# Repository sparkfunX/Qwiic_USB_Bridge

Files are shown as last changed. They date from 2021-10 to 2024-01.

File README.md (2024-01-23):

SparkFun Qwiic USB Development Kit - SAMD21
========================================

Qwiic USB Development Kit - SAMD21 (https://www.sparkfun.com/products/24639)

[*Qwiic USB Development Kit - SAMD21 (SPX-24639)*](https://www.sparkfun.com/products/24639)

The Qwiic USB Development kit is designed for folks that want to interface a Qwiic device quickly and easily to a computer. The core processor is the SAM21 which allows quick (hah!) and seamless serial printing over USB, as well as easy development and programming using the Arduino environment. The professional printed enclosure makes the device easy to plug/unplug as well as allowing Qwiic boards to be mounted to the enclosure itself.

The development kit features two Qwiic connectors and a user-addressable WS2812 LED. In case you need more IO, there are four GPIO pins, accessible by removing the enclosure, two of which are ADC pins. This little device is not only a great tool for making compact prototypes, but a handy way to add Qwiic sensors to your PC-based projects.

Repository Contents
-------------------

* **/Documentation** - Data sheets, additional product information
* **/Enclosure** - Enclosure files 
* **/Firmware** - Example code 
* **/Hardware** - Eagle design files (.brd, .sch)
* **/Production** - Production panel files (.brd)

License Information
-------------------

This product is _**open source**_! 

Please review the LICENSE.md file for license information. 

If you have any questions or concerns on licensing, please contact technical support on our [SparkFun forums](https://forum.sparkfun.com/viewforum.php?f=152).

Distributed as-is; no warranty is given.

- Your friends at SparkFun.

_<COLLABORATION CREDIT>_

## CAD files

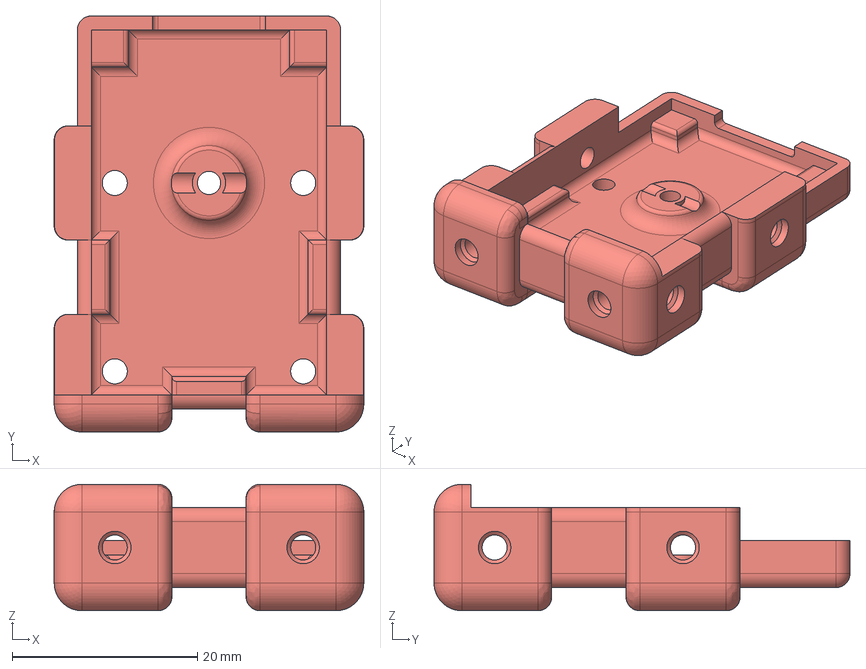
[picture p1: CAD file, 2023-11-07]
Mechanical/Solids/BODY.step
33.4 x 44.9 x 13.6 mm

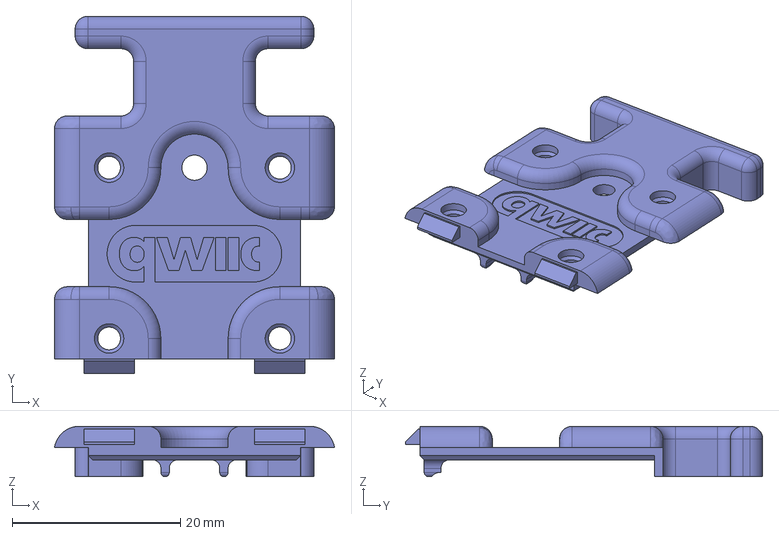
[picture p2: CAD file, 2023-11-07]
Mechanical/Solids/LID.step
33.3 x 42.5 x 6.00 mm

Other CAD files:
Mechanical/Qwiic_USB_Bridge_3DP v28.f3z
Mechanical/Solids/Body.stl
Mechanical/Solids/Lid.stl

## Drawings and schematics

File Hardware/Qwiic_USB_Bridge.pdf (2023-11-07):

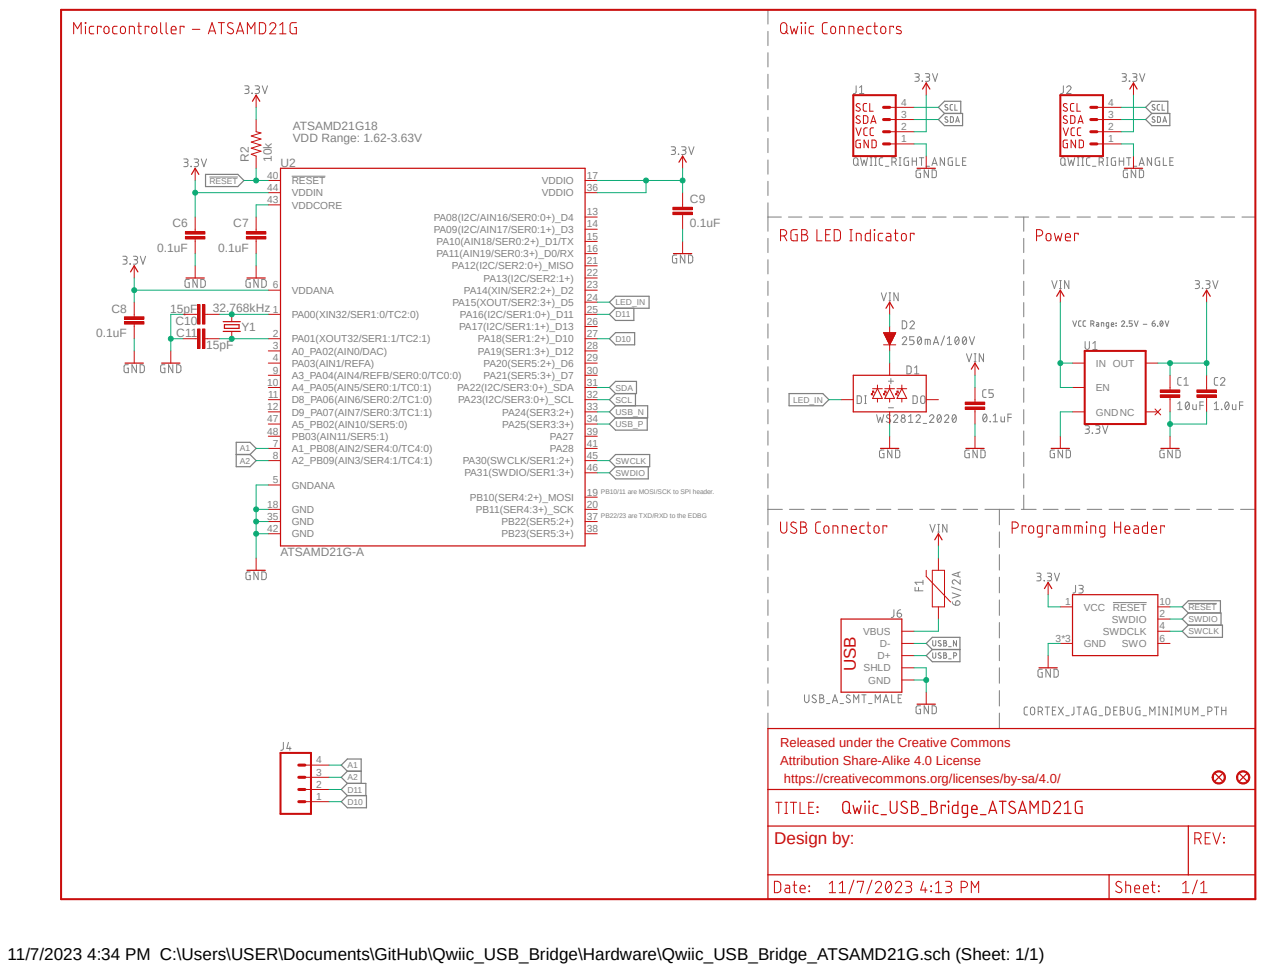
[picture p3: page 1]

PB10/11 are MOSI/SCK to SPI header.

PB22/23 are TXD/RXD to the EDBG

Released under the Creative Commons
Attribution Share-Alike 4.0 License
https://creativecommons.org/licenses/by-sa/4.0/

11/7/2023 4:34 PM C:\Users\USER\Documents\GitHub\Qwiic_USB_Bridge\Hardware\Qwiic_USB_Bridge_ATSAMD21G.sch (Sheet: 1/1)

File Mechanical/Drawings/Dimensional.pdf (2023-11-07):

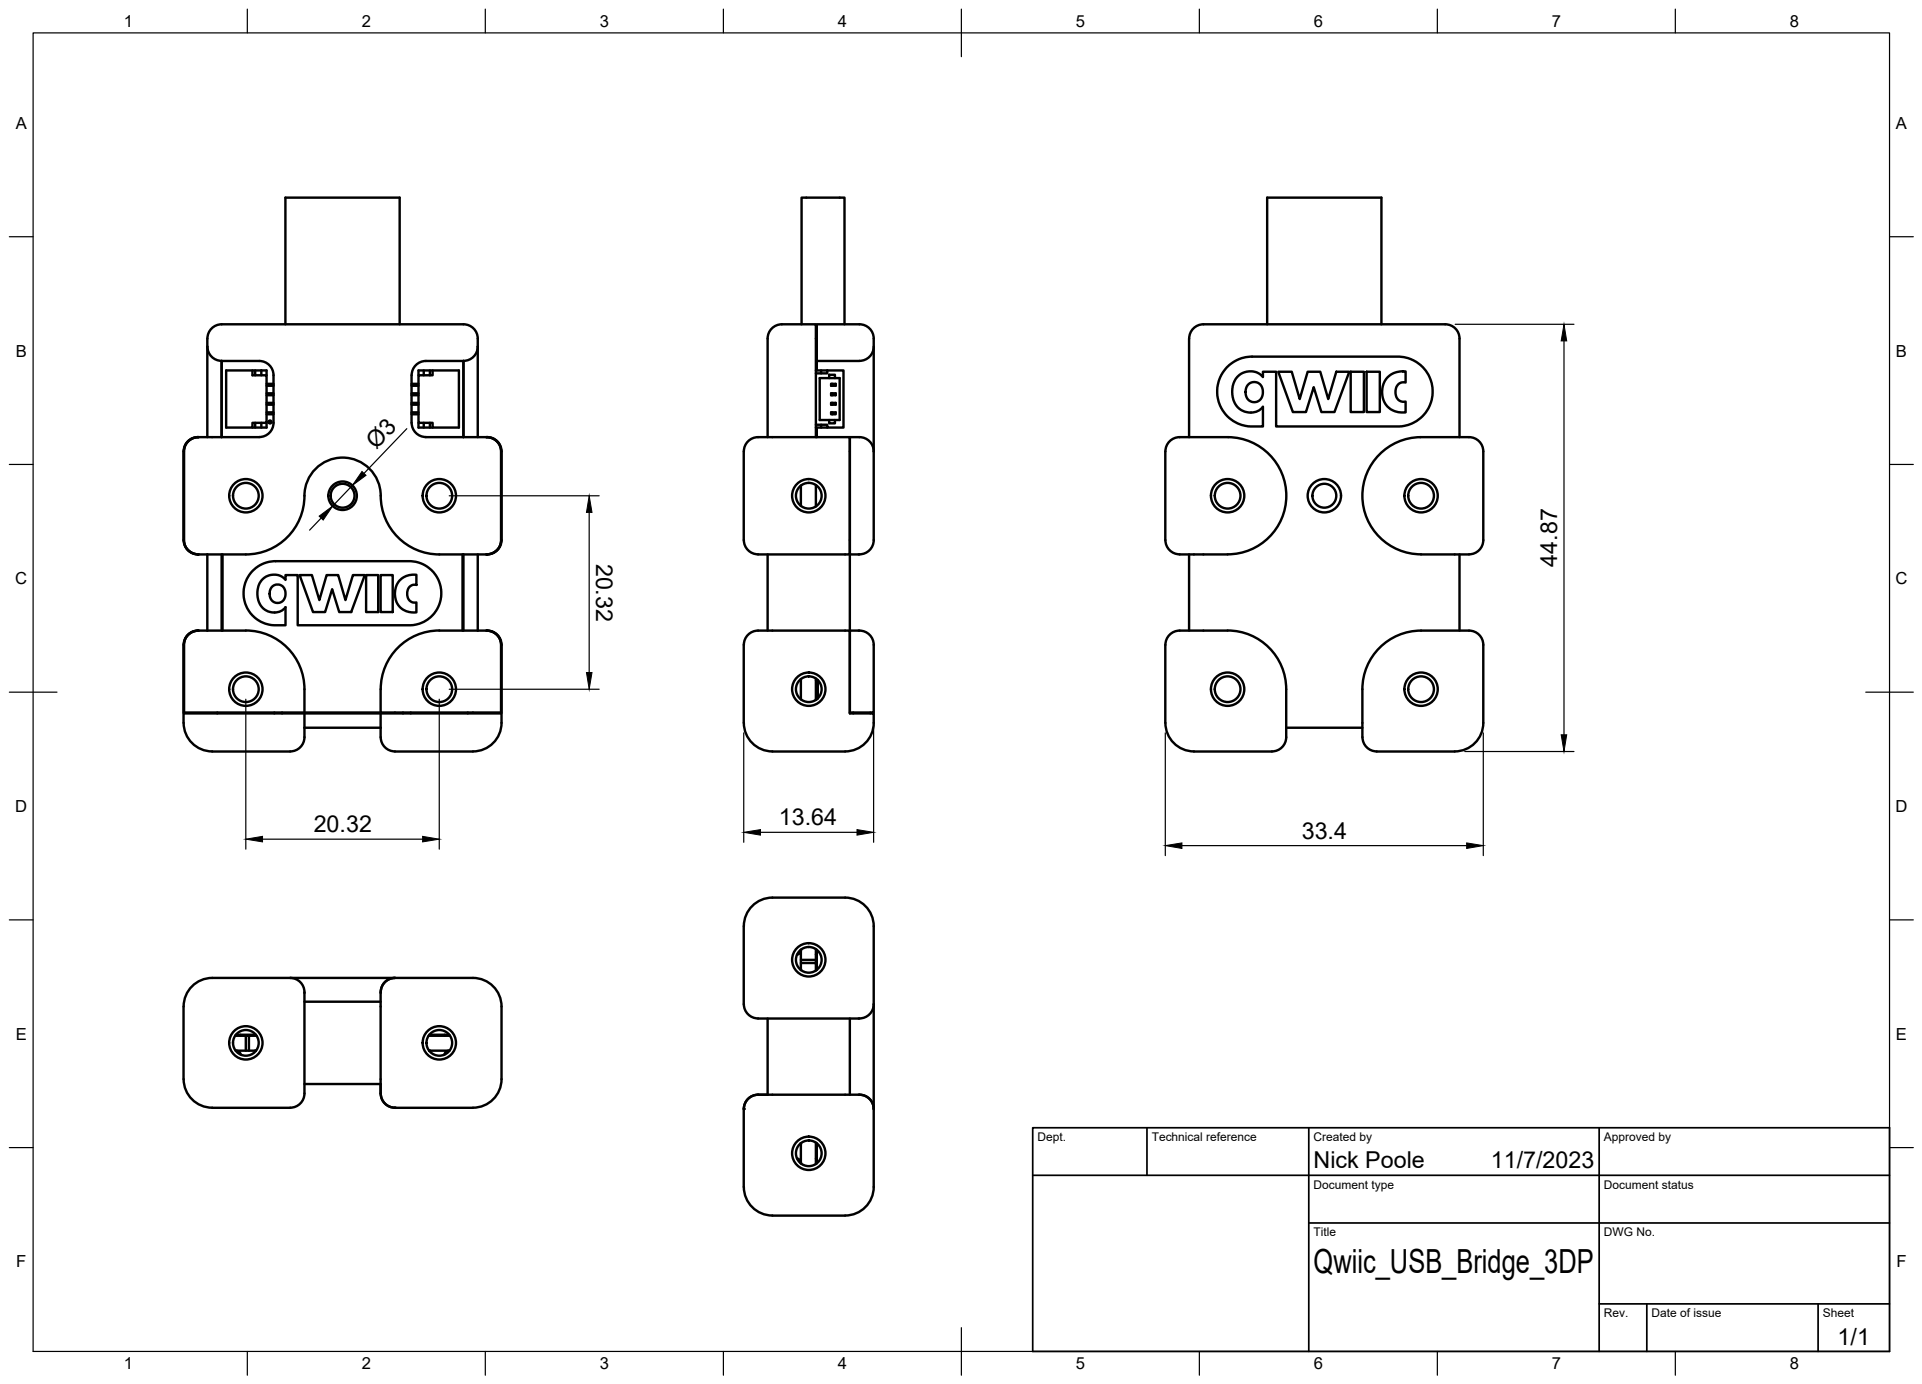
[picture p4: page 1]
Title; DWG No.; Rev.; Date of issue; Sheet

Dept. | Technical reference | Created by Nick Poole 11/7/2023 | Approved by

Document type | Document status

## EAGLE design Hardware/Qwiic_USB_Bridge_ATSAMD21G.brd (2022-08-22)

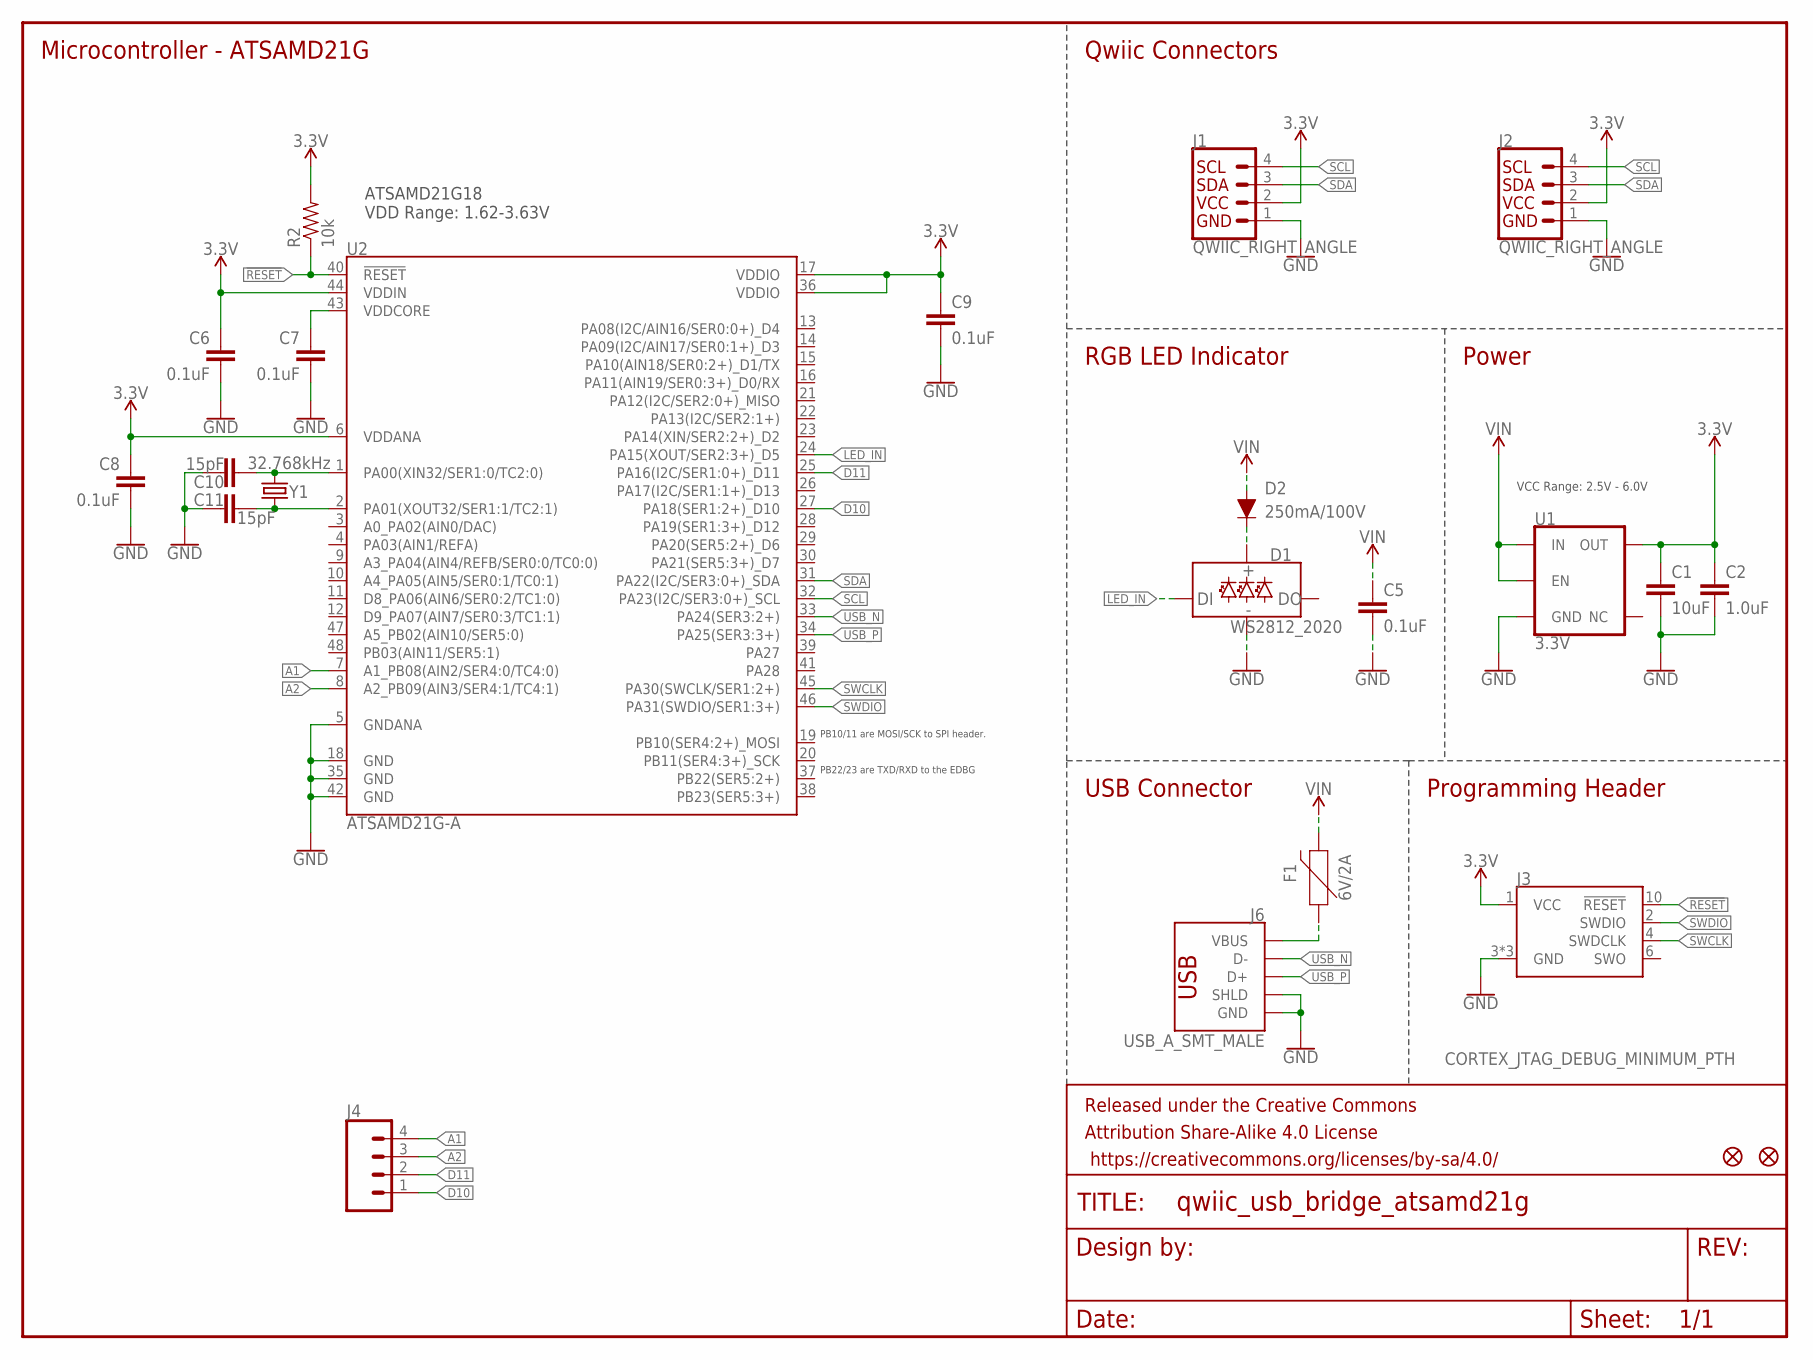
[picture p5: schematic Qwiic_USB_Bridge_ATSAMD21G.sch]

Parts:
C1: 10uF; 0603
C2: 1.0uF; 0603
C5, C6, C7, C8, C9: 0.1uF; 0603
C10, C11: 15pF; 0603
D1: WS2812_2020; WS2812-2020
D2: 250mA/100V; SOD-323
F1: 6V/2A; 1210
FD1, FD2: FIDUCIALUFIDUCIAL; FIDUCIAL-MICRO
FRAME2: FRAME-LETTER; CREATIVE_COMMONS
J1, J2: QWIIC_RIGHT_ANGLE; JST04_1MM_RA
J3: CORTEX_JTAG_DEBUG_MINIMUM_PTH; 2X5-PTH-1.27MM
J4: CONN_041X04_NO_SILK; 1X04_NO_SILK
J6: USB_A_SMT_MALE; USB-A-SMT-MALE
R2: 10k; 0603
U1: 3.3V; SOT23-5
U2: ATSAMD21G-A; TQFP-48
Y1: 32.768kHz; CRYSTAL-SMD-3.2X1.5MM

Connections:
3.3V: C1.1, C2.1, C6.1, C8.1, C9.1, J1.2, J2.2, J3.1 (VCC), R2.2, U1.5 (OUT), U2.6 (VDDANA), U2.17 (VDDIO), U2.36 (VDDIO), U2.44 (VDDIN)
!RESET: J3.10 (!RESET), R2.1, U2.40 (!RESET!)
A1: J4.4, U2.7 (A1_PB08(AIN2/SER4:0/TC4:0))
A2: J4.3, U2.8 (A2_PB09(AIN3/SER4:1/TC4:1))
D10: J4.1, U2.27 (PA18(SER1:2+)_D10)
D11: J4.2, U2.25 (PA16(I2C/SER1:0+)_D11)
GND: C1.2, C2.2, C5.2, C6.2, C7.2, C8.2, C9.2, C10.1, C11.2, D1.GND, J1.1, J2.1, J3.3 (GND), J3.5 (GND), J3.9 (GND), J6.GND1 (GND), J6.SHLD1 (SHLD), J6.SHLD2 (SHLD), U1.2 (GND), U2.5 (GNDANA), U2.18 (GND), U2.35 (GND), U2.42 (GND)
LED_IN: D1.DI, U2.24 (PA15(XOUT/SER2:3+)_D5)
unnamed: F1.1, J6.VBUS1 (VBUS)
unnamed: D1.VCC, D2.C
unnamed: C10.2, U2.1 (PA00(XIN32/SER1:0/TC2:0)), Y1.P$2 (2)
unnamed: C11.1, U2.2 (PA01(XOUT32/SER1:1/TC2:1)), Y1.P$1 (1)
SCL: J1.4, J2.4, U2.32 (PA23(I2C/SER3:0+)_SCL)
SDA: J1.3, J2.3, U2.31 (PA22(I2C/SER3:0+)_SDA)
SWCLK: J3.4 (SWDCLK), U2.45 (PA30(SWCLK/SER1:2+))
SWDIO: J3.2 (SWDIO), U2.46 (PA31(SWDIO/SER1:3+))
USB_N: J6.D-1 (D-), U2.33 (PA24(SER3:2+))
USB_P: J6.D+1 (D+), U2.34 (PA25(SER3:3+))
VDDCORE1: C7.1, U2.43 (VDDCORE)
VIN: C5.1, D2.A, F1.2, U1.1 (IN), U1.3 (EN)

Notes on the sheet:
Qwiic Connectors
RGB LED Indicator
Power
Microcontroller - ATSAMD21G
VCC Range: 2.5V - 6.0V
USB Connector
Programming Header
PB22/23 are TXD/RXD to the EDBG
PB10/11 are MOSI/SCK to SPI header.
ATSAMD21G18 VDD Range: 1.62-3.63V

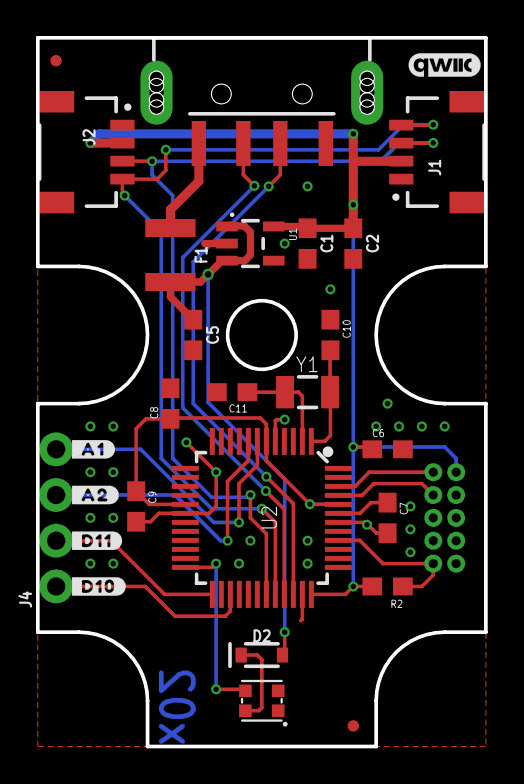
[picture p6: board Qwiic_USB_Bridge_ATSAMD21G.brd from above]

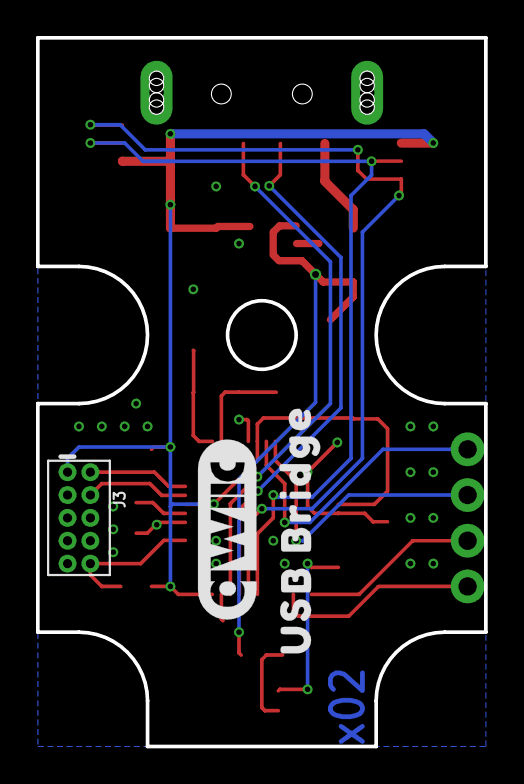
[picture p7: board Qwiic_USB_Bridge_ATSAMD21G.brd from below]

Board: 2 copper layers, 24.9 x 39.4 mm, 31 parts (3 on the bottom side), 20 nets.

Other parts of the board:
U$1: #_A1#0
U$2: #_A2#0
U$3: #_D11#0
U$4: #_D10#0
U$7: QWIIC_10MM
U$8: USB_BRIDGE0
U$9: QWIIC_4MM

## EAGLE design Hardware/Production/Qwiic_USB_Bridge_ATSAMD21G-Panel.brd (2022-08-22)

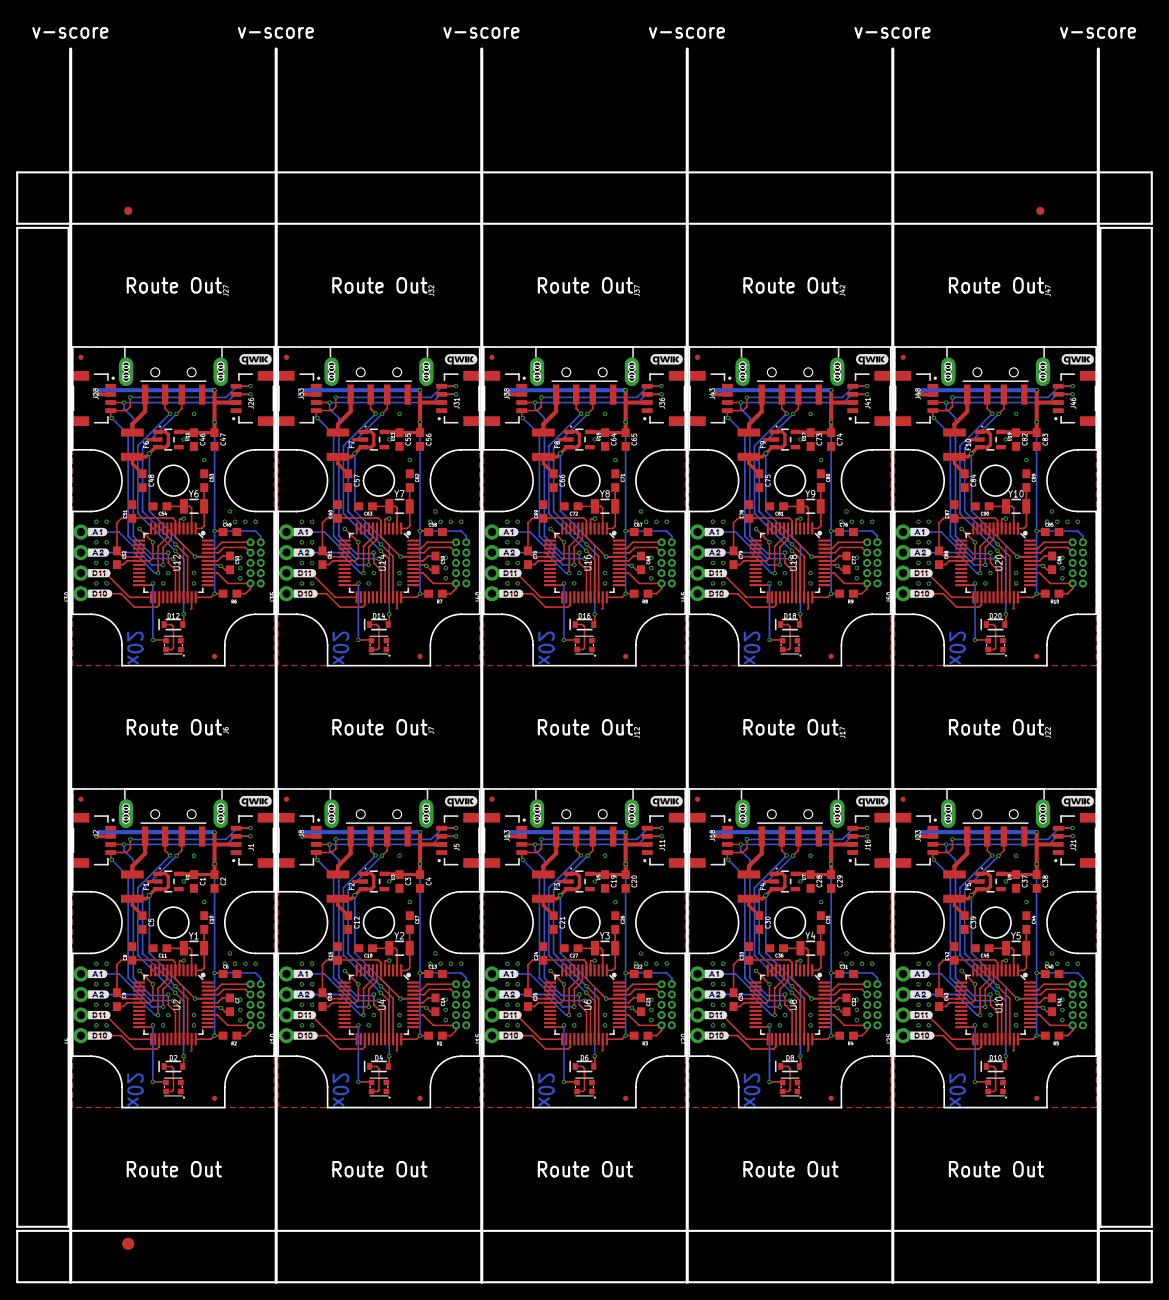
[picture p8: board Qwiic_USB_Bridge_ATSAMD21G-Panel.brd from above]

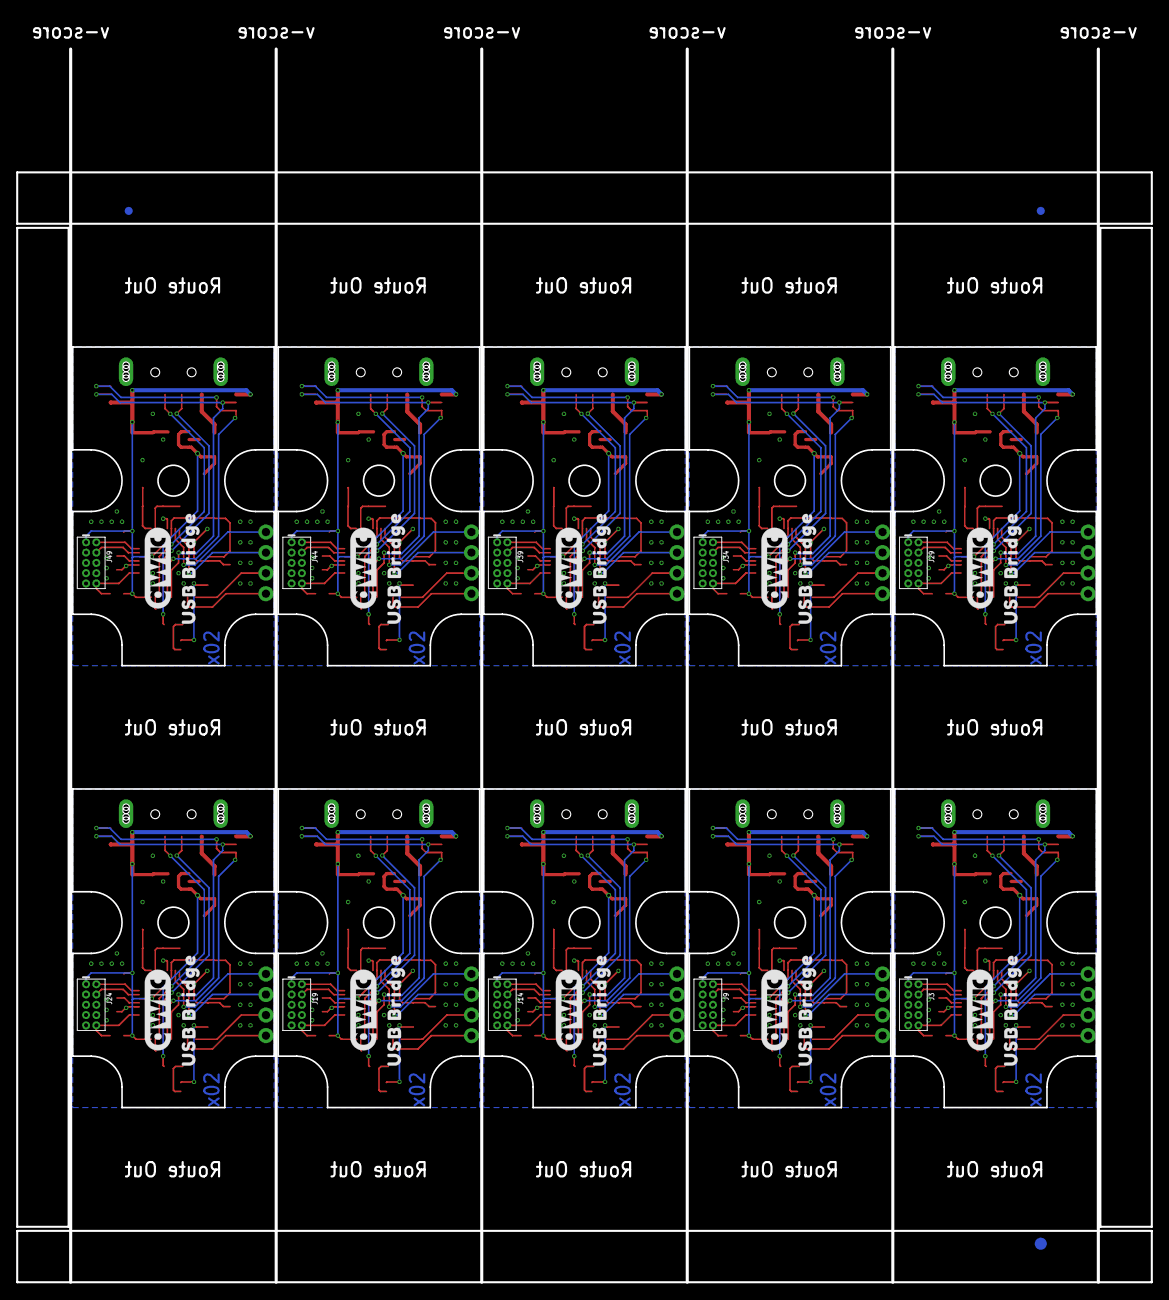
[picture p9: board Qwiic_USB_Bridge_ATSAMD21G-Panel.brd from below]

Board: 2 copper layers, 140.2 x 152.4 mm, 306 parts (33 on the bottom side), 200 nets.

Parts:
C1, C3, C19, C28, C37, C46, C55, C64, C73, C82: 10uF; 0603
C2, C4, C20, C29, C38, C47, C56, C65, C74, C83: 1.0uF; 0603
C5, C6, C7, C8, C9, C12, C13, C14, C15, C16, C21, C22, C23, C24, C25, C30, C31, C32, C33, C34, C39, C40, C41, C42, C43, C48, C49, C50, C51, C52, C57, C58, C59, C60, C61, C66, C67, C68, C69, C70, C75, C76, C77, C78, C79, C84, C85, C86, C87, C88: 0.1uF; 0603
C10, C11, C17, C18, C26, C27, C35, C36, C44, C45, C53, C54, C62, C63, C71, C72, C80, C81, C89, C90: 15pF; 0603
D1, D3, D5, D7, D9, D11, D13, D15, D17, D19: WS2812_2020; WS2812-2020
D2, D4, D6, D8, D10, D12, D14, D16, D18, D20: 250mA/100V; SOD-323
E$1, E$2, E$3, E$4: FIDUCIAL-1X2
E$5, E$6: FIDUCIAL-1.5X3
F1, F2, F3, F4, F5, F6, F7, F8, F9, F10: 6V/2A; 1210
FD1, FD2, FD3, FD4, FD5, FD6, FD7, FD8, FD9, FD10, FD11, FD12, FD13, FD14, FD15, FD16, FD17, FD18, FD19, FD20: FIDUCIALUFIDUCIAL; FIDUCIAL-MICRO
J1, J2, J5, J8, J11, J13, J16, J18, J21, J23, J26, J28, J31, J33, J36, J38, J41, J43, J46, J48: QWIIC_RIGHT_ANGLE; JST04_1MM_RA
J3, J9, J14, J19, J24, J29, J34, J39, J44, J49: CORTEX_JTAG_DEBUG_MINIMUM_PTH; 2X5-PTH-1.27MM
J4, J10, J15, J20, J25, J30, J35, J40, J45, J50: 1X04_NO_SILK
J6, J7, J12, J17, J22, J27, J32, J37, J42, J47: USB_A_SMT_MALE; USB-A-SMT-MALE
R1, R2, R3, R4, R5, R6, R7, R8, R9, R10: 10k; 0603
U1, U3, U5, U7, U9, U11, U13, U15, U17, U19: 3.3V; SOT23-5
U2, U4, U6, U8, U10, U12, U14, U16, U18, U20: ATSAMD21G-A; TQFP-48
U$1, U$11, U$18, U$25, U$32, U$39, U$46, U$53, U$60, U$67: #_A1#0
U$2, U$12, U$19, U$26, U$33, U$40, U$47, U$54, U$61, U$68: #_A2#0
U$3, U$13, U$20, U$27, U$34, U$41, U$48, U$55, U$62, U$69: #_D11#0
U$4, U$14, U$21, U$28, U$35, U$42, U$49, U$56, U$63, U$70: #_D10#0
U$5, U$7, U$15, U$22, U$29, U$36, U$43, U$50, U$57, U$64: QWIIC_10MM
U$6, U$8, U$16, U$23, U$30, U$37, U$44, U$51, U$58, U$65: USB_BRIDGE0
U$9, U$10, U$17, U$24, U$31, U$38, U$45, U$52, U$59, U$66: QWIIC_4MM
Y1, Y2, Y3, Y4, Y5, Y6, Y7, Y8, Y9, Y10: 32.768kHz; CRYSTAL-SMD-3.2X1.5MM

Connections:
3.3V: C1.1, C2.1, C6.1, C8.1, C9.1, J1.2, J2.2, J3.1, R2.2, U1.5, U2.6, U2.17, U2.36, U2.44
3.3V1: C3.1, C4.1, C13.1, C15.1, C16.1, J5.2, J8.2, J9.1, R1.2, U3.5, U4.6, U4.17, U4.36, U4.44
3.3V2: C19.1, C20.1, C22.1, C24.1, C25.1, J11.2, J13.2, J14.1, R3.2, U5.5, U6.6, U6.17, U6.36, U6.44
3.3V3: C28.1, C29.1, C31.1, C33.1, C34.1, J16.2, J18.2, J19.1, R4.2, U7.5, U8.6, U8.17, U8.36, U8.44
3.3V4: C37.1, C38.1, C40.1, C42.1, C43.1, J21.2, J23.2, J24.1, R5.2, U9.5, U10.6, U10.17, U10.36, U10.44
3.3V5: C46.1, C47.1, C49.1, C51.1, C52.1, J26.2, J28.2, J29.1, R6.2, U11.5, U12.6, U12.17, U12.36, U12.44
3.3V6: C55.1, C56.1, C58.1, C60.1, C61.1, J31.2, J33.2, J34.1, R7.2, U13.5, U14.6, U14.17, U14.36, U14.44
3.3V7: C64.1, C65.1, C67.1, C69.1, C70.1, J36.2, J38.2, J39.1, R8.2, U15.5, U16.6, U16.17, U16.36, U16.44
3.3V8: C73.1, C74.1, C76.1, C78.1, C79.1, J41.2, J43.2, J44.1, R9.2, U17.5, U18.6, U18.17, U18.36, U18.44
3.3V9: C82.1, C83.1, C85.1, C87.1, C88.1, J46.2, J48.2, J49.1, R10.2, U19.5, U20.6, U20.17, U20.36, U20.44
!RESET: J3.10, R2.1, U2.40
!RESET1: J9.10, R1.1, U4.40
!RESET2: J14.10, R3.1, U6.40
!RESET3: J19.10, R4.1, U8.40
!RESET4: J24.10, R5.1, U10.40
!RESET5: J29.10, R6.1, U12.40
!RESET6: J34.10, R7.1, U14.40
!RESET7: J39.10, R8.1, U16.40
!RESET8: J44.10, R9.1, U18.40
!RESET9: J49.10, R10.1, U20.40
A1: J4.4, U2.7
A2: J4.3, U2.8
A3: J10.4, U4.7
A4: J10.3, U4.8
A5: J15.4, U6.7
A6: J15.3, U6.8
A7: J20.4, U8.7
A8: J20.3, U8.8
A9: J25.4, U10.7
A10: J25.3, U10.8
A11: J30.4, U12.7
A12: J30.3, U12.8
A13: J35.4, U14.7
A14: J35.3, U14.8
A15: J40.4, U16.7
A16: J40.3, U16.8
A17: J45.4, U18.7
A18: J45.3, U18.8
A19: J50.4, U20.7
A20: J50.3, U20.8
D1: J10.2, U4.25
D2: J10.1, U4.27
D3: J15.2, U6.25
D4: J15.1, U6.27
D5: J20.2, U8.25
D6: J20.1, U8.27
D7: J25.2, U10.25
D8: J25.1, U10.27
D9: J30.2, U12.25
D10: J4.1, U2.27
D11: J4.2, U2.25
D12: J30.1, U12.27
D13: J35.2, U14.25
D14: J35.1, U14.27
D15: J40.2, U16.25
D16: J40.1, U16.27
D17: J45.2, U18.25
D18: J45.1, U18.27
D19: J50.2, U20.25
D20: J50.1, U20.27
GND: C1.2, C2.2, C5.2, C6.2, C7.2, C8.2, C9.2, C10.1, C11.2, D1.GND, J1.1, J2.1, J3.3, J3.5, J3.9, J6.GND1, J6.SHLD1, J6.SHLD2, U1.2, U2.5, U2.18, U2.35, U2.42
GND1: C3.2, C4.2, C12.2, C13.2, C14.2, C15.2, C16.2, C17.1, C18.2, D3.GND, J5.1, J7.GND1, J7.SHLD1, J7.SHLD2, J8.1, J9.3, J9.5, J9.9, U3.2, U4.5, U4.18, U4.35, U4.42
GND2: C19.2, C20.2, C21.2, C22.2, C23.2, C24.2, C25.2, C26.1, C27.2, D5.GND, J11.1, J12.GND1, J12.SHLD1, J12.SHLD2, J13.1, J14.3, J14.5, J14.9, U5.2, U6.5, U6.18, U6.35, U6.42
GND3: C28.2, C29.2, C30.2, C31.2, C32.2, C33.2, C34.2, C35.1, C36.2, D7.GND, J16.1, J17.GND1, J17.SHLD1, J17.SHLD2, J18.1, J19.3, J19.5, J19.9, U7.2, U8.5, U8.18, U8.35, U8.42
GND4: C37.2, C38.2, C39.2, C40.2, C41.2, C42.2, C43.2, C44.1, C45.2, D9.GND, J21.1, J22.GND1, J22.SHLD1, J22.SHLD2, J23.1, J24.3, J24.5, J24.9, U9.2, U10.5, U10.18, U10.35, U10.42
GND5: C46.2, C47.2, C48.2, C49.2, C50.2, C51.2, C52.2, C53.1, C54.2, D11.GND, J26.1, J27.GND1, J27.SHLD1, J27.SHLD2, J28.1, J29.3, J29.5, J29.9, U11.2, U12.5, U12.18, U12.35, U12.42
GND6: C55.2, C56.2, C57.2, C58.2, C59.2, C60.2, C61.2, C62.1, C63.2, D13.GND, J31.1, J32.GND1, J32.SHLD1, J32.SHLD2, J33.1, J34.3, J34.5, J34.9, U13.2, U14.5, U14.18, U14.35, U14.42
GND7: C64.2, C65.2, C66.2, C67.2, C68.2, C69.2, C70.2, C71.1, C72.2, D15.GND, J36.1, J37.GND1, J37.SHLD1, J37.SHLD2, J38.1, J39.3, J39.5, J39.9, U15.2, U16.5, U16.18, U16.35, U16.42
GND8: C73.2, C74.2, C75.2, C76.2, C77.2, C78.2, C79.2, C80.1, C81.2, D17.GND, J41.1, J42.GND1, J42.SHLD1, J42.SHLD2, J43.1, J44.3, J44.5, J44.9, U17.2, U18.5, U18.18, U18.35, U18.42
GND9: C82.2, C83.2, C84.2, C85.2, C86.2, C87.2, C88.2, C89.1, C90.2, D19.GND, J46.1, J47.GND1, J47.SHLD1, J47.SHLD2, J48.1, J49.3, J49.5, J49.9, U19.2, U20.5, U20.18, U20.35, U20.42
LED_IN: D1.DI, U2.24
LED_IN1: D3.DI, U4.24
LED_IN2: D5.DI, U6.24
LED_IN3: D7.DI, U8.24
LED_IN4: D9.DI, U10.24
LED_IN5: D11.DI, U12.24
LED_IN6: D13.DI, U14.24
LED_IN7: D15.DI, U16.24
LED_IN8: D17.DI, U18.24
LED_IN9: D19.DI, U20.24
unnamed: F1.1, J6.VBUS1
unnamed: D1.VCC, D2.C
unnamed: C10.2, U2.1, Y1.P$2
unnamed: C11.1, U2.2, Y1.P$1
unnamed: D3.VCC, D4.C
unnamed: F2.1, J7.VBUS1
unnamed: C17.2, U4.1, Y2.P$2
unnamed: C18.1, U4.2, Y2.P$1
unnamed: D5.VCC, D6.C
unnamed: F3.1, J12.VBUS1
unnamed: C26.2, U6.1, Y3.P$2
unnamed: C27.1, U6.2, Y3.P$1
unnamed: D7.VCC, D8.C
unnamed: F4.1, J17.VBUS1
unnamed: C35.2, U8.1, Y4.P$2
unnamed: C36.1, U8.2, Y4.P$1
unnamed: D9.VCC, D10.C
unnamed: F5.1, J22.VBUS1
unnamed: C44.2, U10.1, Y5.P$2
unnamed: C45.1, U10.2, Y5.P$1
unnamed: D11.VCC, D12.C
unnamed: F6.1, J27.VBUS1
unnamed: C53.2, U12.1, Y6.P$2
unnamed: C54.1, U12.2, Y6.P$1
unnamed: D13.VCC, D14.C
unnamed: F7.1, J32.VBUS1
unnamed: C62.2, U14.1, Y7.P$2
unnamed: C63.1, U14.2, Y7.P$1
unnamed: D15.VCC, D16.C
unnamed: F8.1, J37.VBUS1
unnamed: C71.2, U16.1, Y8.P$2
unnamed: C72.1, U16.2, Y8.P$1
unnamed: D17.VCC, D18.C
unnamed: F9.1, J42.VBUS1
unnamed: C80.2, U18.1, Y9.P$2
unnamed: C81.1, U18.2, Y9.P$1
unnamed: D19.VCC, D20.C
unnamed: F10.1, J47.VBUS1
unnamed: C89.2, U20.1, Y10.P$2
unnamed: C90.1, U20.2, Y10.P$1
SCL: J1.4, J2.4, U2.32
SCL1: J5.4, J8.4, U4.32
SCL2: J11.4, J13.4, U6.32
SCL3: J16.4, J18.4, U8.32
SCL4: J21.4, J23.4, U10.32
SCL5: J26.4, J28.4, U12.32
SCL6: J31.4, J33.4, U14.32
SCL7: J36.4, J38.4, U16.32
SCL8: J41.4, J43.4, U18.32
SCL9: J46.4, J48.4, U20.32
SDA: J1.3, J2.3, U2.31
SDA1: J5.3, J8.3, U4.31
SDA2: J11.3, J13.3, U6.31
SDA3: J16.3, J18.3, U8.31
SDA4: J21.3, J23.3, U10.31
SDA5: J26.3, J28.3, U12.31
SDA6: J31.3, J33.3, U14.31
SDA7: J36.3, J38.3, U16.31
SDA8: J41.3, J43.3, U18.31
SDA9: J46.3, J48.3, U20.31
SWCLK: J3.4, U2.45
SWCLK1: J9.4, U4.45
SWCLK2: J14.4, U6.45
SWCLK3: J19.4, U8.45
SWCLK4: J24.4, U10.45
SWCLK5: J29.4, U12.45
SWCLK6: J34.4, U14.45
SWCLK7: J39.4, U16.45
SWCLK8: J44.4, U18.45
SWCLK9: J49.4, U20.45
SWDIO: J3.2, U2.46
SWDIO1: J9.2, U4.46
SWDIO2: J14.2, U6.46
SWDIO3: J19.2, U8.46
SWDIO4: J24.2, U10.46
SWDIO5: J29.2, U12.46
SWDIO6: J34.2, U14.46
SWDIO7: J39.2, U16.46
SWDIO8: J44.2, U18.46
SWDIO9: J49.2, U20.46
USB_N: J6.D-1, U2.33
USB_N1: J7.D-1, U4.33
USB_N2: J12.D-1, U6.33
USB_N3: J17.D-1, U8.33
USB_N4: J22.D-1, U10.33
USB_N5: J27.D-1, U12.33
USB_N6: J32.D-1, U14.33
USB_N7: J37.D-1, U16.33
USB_N8: J42.D-1, U18.33
USB_N9: J47.D-1, U20.33
USB_P: J6.D+1, U2.34
USB_P1: J7.D+1, U4.34
USB_P2: J12.D+1, U6.34
USB_P3: J17.D+1, U8.34
USB_P4: J22.D+1, U10.34
USB_P5: J27.D+1, U12.34
USB_P6: J32.D+1, U14.34
USB_P7: J37.D+1, U16.34
USB_P8: J42.D+1, U18.34
USB_P9: J47.D+1, U20.34
VDDCORE1: C7.1, U2.43
VDDCORE2: C14.1, U4.43
VDDCORE3: C23.1, U6.43
VDDCORE4: C32.1, U8.43
VDDCORE5: C41.1, U10.43
VDDCORE6: C50.1, U12.43
VDDCORE7: C59.1, U14.43
VDDCORE8: C68.1, U16.43
VDDCORE9: C77.1, U18.43
VDDCORE10: C86.1, U20.43
VIN: C5.1, D2.A, F1.2, U1.1, U1.3
VIN1: C12.1, D4.A, F2.2, U3.1, U3.3
VIN2: C21.1, D6.A, F3.2, U5.1, U5.3
VIN3: C30.1, D8.A, F4.2, U7.1, U7.3
VIN4: C39.1, D10.A, F5.2, U9.1, U9.3
VIN5: C48.1, D12.A, F6.2, U11.1, U11.3
VIN6: C57.1, D14.A, F7.2, U13.1, U13.3
VIN7: C66.1, D16.A, F8.2, U15.1, U15.3
VIN8: C75.1, D18.A, F9.2, U17.1, U17.3
VIN9: C84.1, D20.A, F10.2, U19.1, U19.3

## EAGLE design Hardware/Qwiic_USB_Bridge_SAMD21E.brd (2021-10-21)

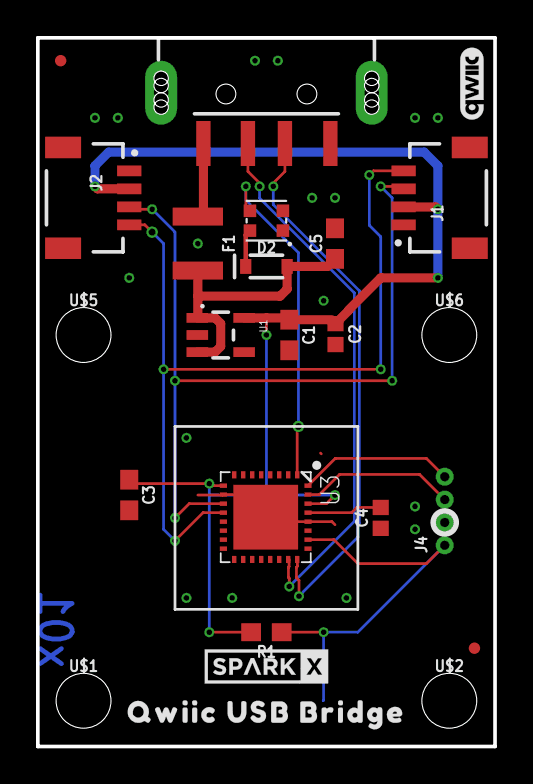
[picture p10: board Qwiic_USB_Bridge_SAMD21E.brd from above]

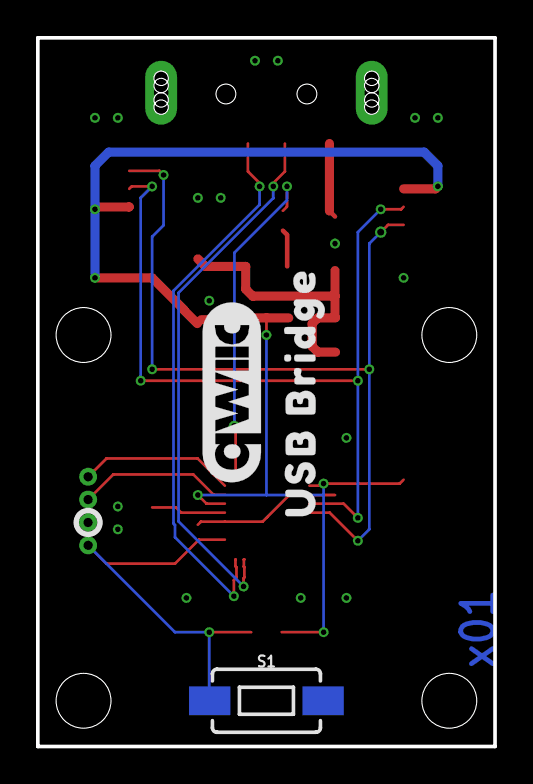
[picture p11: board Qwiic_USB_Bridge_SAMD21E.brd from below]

Board: 2 copper layers, 25.4 x 39.4 mm, 28 parts (3 on the bottom side), 14 nets.

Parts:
C1, C3: 10uF; 0603
C2, C4: 1.0uF; 0402
C5: 0.1uF; 0603
D1: WS2812_2020; WS2812-2020
D2: 250mA/100V; SOD-323
F1: 6V/2A; 1210
FD1, FD2: FIDUCIALUFIDUCIAL; FIDUCIAL-MICRO
FRAME2: FRAME-LETTER; CREATIVE_COMMONS
J1, J2: QWIIC_RIGHT_ANGLE; JST04_1MM_RA
J4: 1X04_1.27MM_NO_SILK
J6: USB_A_SMT_MALE; USB-A-SMT-MALE
R1: 10k; 0603
S1: MOMENTARY-SWITCH-SPST-SMD-6.0X3.5MM; TACTILE_SWITCH_SMD_6.0X3.5MM
U1: 3.3V; SOT23-5
U3: ATSAMD21E18A-U; QFN-32_SAMD
U$1, U$2, U$5, U$6: STAND-OFF-TIGHT
U$3: QWIIC_USB_BRIDGE0
U$4: SPARKX-SMALL
U$7: QWIIC_10MM
U$8: USB_BRIDGE0
U$9: QWIIC_4MM

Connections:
3.3V: C1.1, C2.1, C3.1, J1.2, J2.2, R1.2, U1.5, U3.VDD, U3.VDDIN
!RESET: J4.1, R1.1, S1.1, U3.RES
GND: C1.2, C2.2, C3.2, C4.1, C5.2, D1.GND, J1.1, J2.1, J4.2, J6.GND1, J6.SHLD1, J6.SHLD2, S1.2, U1.2, U3.GND, U3.GNDANA, U3.PAD
LED_IN: D1.DI, U3.PA00
unnamed: F1.1, J6.VBUS1
unnamed: D1.VCC, D2.C
SCL: J1.4, J2.4, U3.PA09
SDA: J1.3, J2.3, U3.PA08
SWCLK: J4.3, U3.PA30
SWDIO: J4.4, U3.PA31
USB_N: J6.D-1, U3.PA24
USB_P: J6.D+1, U3.PA25
VDDCORE: C4.2, U3.VDDCORE
VIN: C5.1, D2.A, F1.2, U1.1, U1.3

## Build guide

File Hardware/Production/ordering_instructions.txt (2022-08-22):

panel size, 141x138mm
PCB thickness, 1.6mm
number of layers, 2
soldermask color, Unknown
silkscreen color, White
oz copper, 1oz
finish, HASL lead free
stencils, top
pcs per panel, 10
min trace width, 0.2032mm / 0.0080in
min drill size, 0.3048mm / 0.0120in

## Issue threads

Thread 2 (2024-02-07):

Serial does not work

karelv, 2024-02-07:
This is a lovely product. I have put in my sketch and it didn't print anything on the console.

```cpp
void setup()
{
  Serial.begin(115200);  // Start serial for output
}

void loop()
{
  Serial.println("TEST");
  delay(500);
}
```

The compilation and upload goes well:
```
Sketch uses 10436 bytes (3%) of program storage space. Maximum is 262144 bytes.
Global variables use 2980 bytes (9%) of dynamic memory, leaving 29788 bytes for local variables. Maximum is 32768 bytes.
Atmel SMART device 0x10010005 found
Device       : ATSAMD21G18A
Chip ID      : 10010005
Version      : v1.1 [Arduino:XYZ] Jul 25 2022 23:50:06
Address      : 8192
Pages        : 3968
Page Size    : 64 bytes
Total Size   : 248KB
Planes       : 1
Lock Regions : 16
Locked       : none
Security     : false
Boot Flash   : true
BOD          : true
BOR          : true
Arduino      : FAST_CHIP_ERASE
Arduino      : FAST_MULTI_PAGE_WRITE
Arduino      : CAN_CHECKSUM_MEMORY_BUFFER
Erase flash
done in 0.814 seconds

Write 10436 bytes to flash (164 pages)

[===========                   ] 39% (64/164 pages)
[=======================       ] 78% (128/164 pages)
[==============================] 100% (164/164 pages)
done in 0.084 seconds

Verify 10436 bytes of flash with checksum.
Verify successful
done in 0.015 seconds
CPU reset.
```

The terminal stays empty:
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

I'm using Arduino IDE 2.2.1, with the board library:
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

Can you help to get this basic function up and running?

nseidle, 2024-02-07:
Serial points at the physical UART where you are looking at the USB terminal. You will likely need to use SerialUSB.print().

karelv, 2024-02-07:
`SerialUSB` indeed works... It is a little strange as all the other boards I have used are using 'Serial' for their USB one, and Serial1, Serial2, ... for the physical UARTs. But ok, it works! Thanks for pointing this out so quickly.

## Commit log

2021-10-21 PCB x01 protos on order
    [Bottom Shell.iges, Bottom Shell.step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]
2022-04-08 Proto Revision
    Swap out ATSAMD21E for 21G TQFP
    [Qwiic_USB_Bridge_ATSAMD21G.brd, Qwiic_USB_Bridge_ATSAMD21G.sch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]
2022-08-22 Updating to build version
    [Qwiic_USB_Bridge_ATSAMD21G-Panel.brd, Qwiic_USB_Bridge_ATSAMD21G.brd, Qwiic_USB_Bridge_ATSAMD21G.sch]
2023-11-07 Remove Firmware Directory and Update Mechanicals
    [BODY.step, Body.stl, Bottom Shell.iges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]
2023-11-07 Add Schematic PDF

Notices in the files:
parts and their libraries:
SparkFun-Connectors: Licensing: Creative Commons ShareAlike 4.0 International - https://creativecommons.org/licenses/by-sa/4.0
